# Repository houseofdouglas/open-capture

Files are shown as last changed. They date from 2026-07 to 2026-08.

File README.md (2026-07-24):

# open-capture

A fully DIY object-scanning setup for turning real objects into 3D-printable
replicas — **no LiDAR, no NVIDIA GPU, no paid software**. A phone camera plus
a printed motorized turntable feed Apple's built-in photogrammetry engine,
and the result is cleaned up into a printable STL.

It has two halves:

1. **`photogrammetry`** — a tiny macOS command-line wrapper around Apple's
   RealityKit Object Capture. Point it at a folder of photos, get a 3D model.
2. **`scanner_rig/`** — a printable, motorized photogrammetry rig: a turntable
   driven by a 28BYJ-48 stepper and an iPhone cradle, with an ESP32 that
   rotates the table and fires the camera shutter over Bluetooth. One button
   press = one full revolution of evenly spaced photos, hands-free.

## Pipeline

```
object on turntable  ──►  ~144 photos (3 tilt orbits)  ──►  photogrammetry CLI
      ──►  .usdz mesh  ──►  Blender cleanup  ──►  STL  ──►  slice & print
```

## Quick start (software)

Build the photogrammetry CLI (macOS, Apple silicon, Xcode toolchain):

```bash
swiftc -O -parse-as-library -o photogrammetry photogrammetry.swift
```

Reconstruct a model from a folder of photos:

```bash
./photogrammetry ./photos ./model.usdz -d full -f high
```

`-d` detail: `preview | reduced | medium | full | raw`  ·  `-f` feature
sensitivity: `normal | high`. Run a quick `-d medium` pass first to check
photo coverage before committing to a long `full` run.

## The rig

See **[`scanner_rig/README.md`](scanner_rig/README.md)** for the bill of
materials (~$15 of electronics), print list, wiring, and assembly. All parts
are parametric OpenSCAD and print without supports. Firmware and the exact,
verified library versions are in
**[`scanner_rig/firmware/turntable_shutter/`](scanner_rig/firmware/turntable_shutter/)**
(see `LIBRARIES.md` there — the ESP32-C3 needs the NimBLE keyboard stack).

## Capture tips (these matter more than the software)

- Even, diffuse light; matte-coat shiny or featureless objects.
- A **plain, featureless backdrop** behind the turntable — if the software can
  see background texture, it concludes the object never moved and the
  reconstruction fails.
- Lots of overlapping photos from several heights (the cradle's tilt stops).
- Include a ruler in a couple of shots so you can scale the model correctly.

## License

MIT — see [`LICENSE`](LICENSE).

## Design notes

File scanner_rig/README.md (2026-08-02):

# Automated Photogrammetry Scanning Rig

Motorized turntable + tilting iPhone 16 Pro cradle for Object Capture
scans. The ESP32 rotates the table and triggers the iPhone shutter over
Bluetooth (it emulates a volume-up keypress — the native Camera app's
shutter). One button press = one full revolution of evenly spaced photos.

## Bill of materials

| Item | Qty | Notes |
|---|---|---|
| 28BYJ-48 stepper + ULN2003 driver | 1 | sold as a pair, ~$4 |
| ESP32-C3 SuperMini | 1 | 22.52 x 18 mm, 2.54 mm pitch headers |
| 608ZZ bearings (skateboard) | 3 | platter support rollers |
| (printed axle x3) | 3 | snap-in bearing axles — no rod/bolt needed |
| M4 x 8 screws + nuts | 2 | motor ears, bolted through the hub (nut underneath) |
| Zip ties | 2 | lash the ULN2003 board to a spoke |
| M4 x 12 screws | 3 | 2 pivots + 1 angle-lock pin (self-tap into tray bosses) |
| M4 x 12 screws | 4 | crossbars, through each wing into the bar ends (self-tap) |
| M4 x 12 screws | 6 | roller brackets, up through the plate (self-tap into bracket feet) |
| USB cable + 5 V supply | 1 | powers ESP32 and motor |
| Cork or rubber sheet, ~175 mm disc | 1 | optional platter grip, glued to the top face |

## Print

All parts print without supports. PLA or PETG, 3–4 walls, ~25% infill.
PETG note: drive the self-tapping M4 screws slowly — PETG grips hard and
can crack a boss if forced; the pilot holes are sized 3.6 mm for it.

The wing is 238 x 312 mm, so print the two **one at a time** — they won't fit
side by side on a 350 mm bed. Use a brim: it's a long, thin, flat PETG part and
the corners are the most likely thing to lift.

The base is a lightweight spoked frame (motor hub + bracket ring + 3 spokes
+ 3 feet) — about half the filament of a solid disc. Set `solid_base = true`
in `turntable.scad` if you'd rather have the fully enclosed disc + skirt.

| File | Part | Orientation |
|---|---|---|
| `turntable.scad` | `motor_test` (`stl/turntable_motor_test.stl`) | OPTIONAL: dry-fit the motor first (see below) |
| `turntable.scad` | `base_print` (`stl/turntable_base_print.stl`) | pre-flipped: plate face down, skirt up |
| `turntable.scad` | `bracket` x3 (`stl/turntable_bracket.stl`) | foot down |
| `turntable.scad` | `axle` x3 (`stl/turntable_axle.stl`) | flange on the bed, tip up |
| `turntable.scad` | `platter` | **upside down** (hub boss up) — or use `platter_print` / `stl/turntable_platter_print.stl`, which is pre-flipped |
| `phone_cradle.scad` | `tray` | flat on its back |
| `phone_cradle.scad` | `wing` x2 (`stl/cradle_arc_wing.stl`) | flat (238 x 312 x 6) |
| `phone_cradle.scad` | `crossbar` x2 (`stl/cradle_arc_crossbar.stl`) | flat |
| `phone_cradle.scad` | `gauge` (`stl/cradle_setback_gauge.stl`) | flat — holds the stand's setback, see below |
| `phone_cradle.scad` | `chocks` (`stl/cradle_foot_chocks.stl`) | one print = both chocks; locks the position outright |
| `phone_cradle.scad` | `shim` x2 (`stl/cradle_arc_shim.stl`) | only for taller objects — see below |
| `phone_cradle.scad` | `gauge` x1 (`stl/cradle_setback_gauge.stl`) | sets turntable↔stand distance repeatably |
| `phone_cradle.scad` | `chocks` x1 file (`stl/cradle_foot_chocks.stl`) | lock the turntable foot once aligned |

(`stand` is the older flat stand — superseded by the arc wings, see below.)
| `header_pin_jig.scad` (`stl/header_pin_jig.stl`) | OPTIONAL: solder the ESP32-C3 SuperMini's header pins | flat on the bed |

Export from the CLI: `openscad -o platter.stl -D 'part="platter"' turntable.scad`
(pre-exported copies are in `stl/`).

**Soldering the SuperMini's header pins:** print `header_pin_jig.scad`. Snap
two 1x8 segments off a standard break-away header strip and push each,
long-pin-down, into a row of the jig's holes until the plastic shoulder
sits flat on top — same as plugging them into a breadboard. The short pins
now point up ~2.5 mm; lower the SuperMini (component side up) so its two
rows of through-holes slide over them, tack-solder one corner pin per row,
check it sits flat and square, then solder the rest from the top.

Dry-fit before reprinting the base: print `motor_test` and check that
(1) the shaft passes through the center hole, (2) the body drops into the
recess and can rotate freely to any angle, and (3) both ear bolts pass
through the holes with the ears flat. If an ear is off, tweak `mount_c2c`
(spacing) or `mount_perp` (offset) and reprint the coupon until it fits —
then the full base is guaranteed right.

Key parameters to check before printing:

- `turntable.scad` → `shaft_len`: measure your motor's shaft protrusion
  above the mounting flange (typically ~10 mm).
- `phone_cradle.scad` → `fit` / `phone_t`: bump to ~2.0 / case thickness
  if the phone wears a case.
- `phone_cradle.scad` → `obj_h`: where the arc aims — the height of the object's
  **centre** above the table, `69 + objectHeight/2`. Default 101 targets a 64 mm
  object (the 2x sweet spot). **You don't need a wing per object size** — see
  One stand, any object size below.
- `phone_cradle.scad` → `cam_R`: camera-to-object distance. Leave at 200 mm and
  change **zoom** rather than geometry to handle different object sizes — see
  Framing below. This sets the size of the wings, so pick it before printing.

## Why the stand is an arc

Tilting the tray only changes where the camera *aims*, not where it *is*. A
cradle fixed at object height shooting 40° down aims at the tabletop in front
of the object. To shoot down at θ and keep the object centred and the same size
in frame, the camera has to ride an arc of constant radius about the object
centre:

```
y = cam_R·cos θ        z = obj_h + cam_R·sin θ        tilt = θ
```

Higher **and** closer as θ grows. Besides framing, that's also what keeps the
stand short — reaching 65° on an arc needs 271 mm of height, but a straight
column 200 mm back would need **519 mm**:

| elevation | arc: dist / height | straight column: height |
|---|---|---|
| 15° | 193 mm / 142 mm | 144 mm |
| 40° | 153 mm / 219 mm | 258 mm |
| 65° | 85 mm / 271 mm | 519 mm |

The wings' three pivot stations sit on that arc, each with a lock hole that
sets the matching tilt, so the geometry can't be set wrong. Verified in CAD:
the tray clears the wings and crossbars at all three stations, and the stand
stays stable (worst-case CG 23 mm inside the front foot).

## Assemble

**Reusing an already-printed base** (motor and bracket-screw holes moved in
this revision — you do NOT need to reprint the big base): the safest way to
locate the new holes is to use the parts themselves as drill templates.
- Motor: print `motor_drill_template.scad` (`stl/motor_drill_template.stl`).
  Flip it onto the flat plate face — its center pin drops into the shaft
  hole and its locator pin into an old ear hole, fixing position AND
  rotation. Drill through the two guides with a 4.4 mm bit. Old holes stay
  unused. (More precise than free-hand marking through the ears.)
- Brackets: centre a new (reprinted) bracket over each old hole pair, mark
  through its two foot holes, drill Ø4.4. This puts the screws fore & aft
  of the bearing where they belong.
Only the **brackets** must be reprinted (the old ones bury the bearing on
the foot and put screws under it). The platter is fine as-is; reprint it
only if shaft engagement feels shallow.

1. Mount the motor: shaft up through the center hole, body in the recess.
   The 28BYJ-48 shaft is OFFSET from the body centre, so the recess is
   oversized and centred on the shaft — rotate the motor so its two ears
   lie over the bolt holes, then bolt through with M4 x 8 + nuts. (The
   motor carries no load, it only turns the platter, so light retention
   is enough.)
2. Drop a 608ZZ into each bracket's gap and push a printed `axle` through
   from the outer tab — barb first — until it clicks past the far tab and
   the flange seats flush. The bearing spins on the shaft; no rod or bolt
   needed. Screw the three brackets to the plate top with M4 x 12 from
   underneath — the two screws sit fore & aft of the bearing so they can't
   foul it, and the foot is relieved beneath the bearing so the outer race
   spins free.
3. Press the platter's hub onto the D-shaft; its rim rests on the bearings.
   The platter's weight sits on the three bearings, not the motor shaft.
4. Bolt the tray between the uprights (M4 pivots through the big holes,
   self-tapping into the tray bosses). The third M4 through an arc hole
   into the tray's lock hole sets the tilt. Both long walls are relieved
   so the phone's side buttons never get pressed — slide the phone in
   under the two retaining tabs; either orientation works. The window
   is sized so the camera island passes through it and the phone seats
   on the flat glass around it (rather than rocking on the lenses).
5. Wire the ULN2003 (IN1/2/3/4 → GPIO 4/5/6/7, 5 V, GND) and zip-tie the
   board to one of the spokes; the motor and wiring hang in the open frame
   below the platter.

   Bring-up tip: if you want to check the motor and coil wiring before
   committing to the ESP32, `firmware/uno_r4_stepper_test/` runs the same
   coil sequence on an Arduino Uno R4 (IN1-4 → D8-D11) — press a button on
   D2, or type `r` in Serial Monitor, for one revolution. Once that spins
   smoothly, move IN1-4 to the ESP32 GPIOs above and flash
   `turntable_shutter` for real.

   Have a Uno R4 **WiFi**? Its connectivity module is itself a standalone
   ESP32-S3 with its own USB-JTAG/Serial port — `firmware/uno_r4_esp32s3_shutter_test/`
   can be flashed directly onto it (bypassing the RA4M1 main chip entirely)
   to test the BLE-keyboard shutter trick before wiring up the SuperMini.
   See that file's header comment for how to enter direct-flash mode.

## One stand, any object size

`obj_h` is baked into the wings, but it only fixes where the arc *aims*. What
actually matters is the height difference between the wings' base and the object
centre — so change that with a shim instead of reprinting a stand:

```
shim = (object height)/2 + 69 − obj_h      (69 = platter top above the desk)
```

- **positive** → spacer under both wings (`shim` part; set `shim_rise`, print 2)
- **negative** → riser under the object, on the platter (any disc of that height)

At the default `obj_h = 101`:

| object height | shim |
|---|---|
| 20 mm | 22 mm riser under the object |
| 40 mm | 12 mm riser under the object |
| **64 mm** | **none — exact** |
| 80 mm | 8 mm under the wings |
| 100 mm | 18 mm under the wings |
| 130 mm | 33 mm under the wings |
| 160 mm | 48 mm under the wings |

And you can ignore the shim entirely over a useful range, because the object just
sits slightly off-centre in frame rather than badly misaimed: **no shim needed
for 43–85 mm objects at 2x, or 23–105 mm at 1x** (the wider 1x frame is more
forgiving). Only reach for a shim outside those bands.

## Framing — how much of the frame the object should fill

Apple's rule is "maximize the portion of the field of view capturing the
object", but "each image should contain the entirety of the object". For a
turntable that needs one extra constraint: **the object rotates**, so you have
to frame its *widest* rotational profile, not the width you happen to see when
setting up.

**Target ~65% of the short (vertical) frame dimension at the object's widest
rotation.** To check it, **double-press the BOOT button**: the table makes one
full revolution in ~10 s with no photos, so you can watch the preview and
confirm nothing clips at any angle. (Works with no phone paired too, for
exercising the mechanism.)

- Below ~50%: throwing away resolution.
- Above ~80%: the object clips on some rotations, and it sits in the
  lens-distortion zone at the frame edges. Clipped frames cost more than the
  extra detail gains.

At `cam_R = 200 mm`, the vertical frame is almost exactly the camera distance
at 1x, and half that at 2x:

| zoom | vertical frame | detail | 65% fill = object |
|---|---|---|---|
| **1x** (24 mm eq, 24 MP) | 199 mm | 21 px/mm | **130 mm** |
| **2x** (48 mm eq, 12 MP) | 100 mm | 30 px/mm | **65 mm** |

So one printed stand covers roughly **50–160 mm** objects just by switching
zoom — and 2x actually resolves *more* detail per mm than 1x, because it's a
true sensor crop of the 48 MP main camera (not interpolation). Smaller objects
still work at reduced fill: a 30 mm object at 2x is ~900 px across, plenty for
a good mesh. Avoid the 5x lens — it's a separate camera with a much longer
minimum focus distance.

**Keep the zoom locked and identical for all 144 shots** of a session, along
with focus and exposure — Apple asks for consistent focal length, shutter,
aperture and ISO across the set. Never change zoom mid-session.

### Holding the setback (`stl/cradle_setback_gauge.stl`, print 1)

Re-pinning the tray between stations nudges the stand, and any change in setback
changes `cam_R` — so scale, framing and focus distance drift between passes,
which is exactly what the arc exists to prevent.

The gauge is a bar that drops over both wing toes (a slot either side of each
bottom rail) and presents a flat face 11 mm in front of them. Turn the turntable
so **one foot points at the stand**, push it back until that foot touches the
face, and the platter axis is 100 mm from the toes — by geometry, not by eye.

Two things about it are deliberate:

- **The contact is flat, not a pocket.** A flat only fixes fore/aft, so you can
  still slide the turntable sideways to put the lens on the axis (below). A
  pocket capturing the foot would fix the sideways offset too and make the
  ~45–50 mm lens offset unreachable.
- **Aim is forgiving.** As the foot rotates its outer corner sweeps toward the
  contact, so being 10° off costs under 0.2 mm of setback (20° ≈ 1.8 mm). It
  does not need to be squared up carefully.

Verified in CAD: at the stop it touches the foot with zero interference, clears
both wings and the platter, and still clears after sliding the turntable 50 mm
sideways. Print flat as modelled — no supports.

### Locking the position outright (`stl/cradle_foot_chocks.stl`, one print = 2 parts)

The gauge alone only stops the turntable moving *closer*. It can still slide
sideways or pull away, so knocking the stand while re-pinning the tray still
changes the framing and the next pass no longer matches the last.

The chocks finish the job. They are a C-clamp that drops onto the gauge bar from
above (anywhere along it — they never have to slide past the wing-rail guides)
and clamp either side of the captured foot with an M4 self-tap screw:

| direction | what stops it |
|---|---|
| fore | the gauge's flat face on the foot's outer face |
| aft | the chocks' inward hooks catching the foot's inner face |
| lateral | the two chock side faces pinching the foot |
| yaw | those same two faces holding the foot square |

**Yaw is the one that is easy to miss.** The platter axis is located
*indirectly*, 80 mm inboard of the foot, so letting the base rotate swings the
axis even with the foot's position perfectly fixed. That is why the foot is
gripped on both sides rather than simply cornered.

Set them **once, after the lens alignment**, and the sideways offset is
preserved — they clamp anywhere along the bar, so nothing hard-codes an offset
specific to one phone or one landscape orientation. To re-align later, slacken
both screws, slide, retighten.

Drive the screws from **behind**: the reaction pulls the collar onto the bar. A
screw pressing down from the top would jack the chock off it instead.

Measured slack in CAD — seated with zero interference, and colliding as soon as
it moves:

| movement | free until | residual effect |
|---|---|---|
| lateral | 0.5 mm | 0.14° off-axis — negligible |
| pull away | 0.5 mm | 0.25% scale error |
| yaw | under 0.5° | swings the axis 0.7 mm |

Worst case that is ~1.2 mm of axis error, **0.9% of the 133 mm frame width at
2x** — comfortably below what shows up between passes.

To remove the turntable, just lift it out; the hooks are only 12 mm tall against
a 32 mm foot.

### Aligning the lens with the turntable axis

The arc is centred on the tray's pivot, but the iPhone's rear lens is **not** at
the centre of the phone — the camera island sits near one end, roughly 45–50 mm
off centre along the phone's long axis. In landscape that offset is sideways, so
if you line the *stand* up with the turntable axis, the object lands well off
centre in the frame (~14° off axis at 200 mm — near the edge at 2x).

Fix at setup, no parts change: **slide the turntable sideways until the object
is centred in the camera preview**, then mark the spot. Aligning the lens (not
the stand) with the platter axis also makes the camera-to-object distance
exactly `cam_R`. There's a smaller ~9 mm vertical offset too; nudge the
turntable or `obj_h` if the object sits high or low in frame.

Overlap is already comfortable: 48 shots/revolution = 7.5° steps ≈ 96% overlap
between adjacent frames (Apple's minimum is 70%), and 3 orbits × 48 = 144
images (Apple's minimum is 100).

## Uneven advances — drive-train backlash

Symptom: stepping through the shots, some advances look full and others fall
short, at random.

The cause is lost motion between the motor and the platter, and it is much
larger than it looks. The platter's D-bore rides the 28BYJ-48's flatted shaft
with 0.4 mm of clearance across a 3 mm flat — a 1.5 mm moment arm, so that tiny
linear clearance becomes **~6° of free rotation, about 80% of a 7.5° photo
step.** The motor's own plastic gear train adds more on top.

| bore flats | clearance | free rotation | of a 7.5° step |
|---|---|---|---|
| 3.4 (original) | 0.40 mm | 5.97° | 80% |
| 3.2 | 0.20 mm | 2.92° | 39% |
| 3.1 | 0.10 mm | 1.45° | 19% |

Three fixes, in order of effect:

1. **Grub screw in the hub (removes the play, doesn't just shrink it).**
   `hub_grub` adds a radial M3 into the boss, clamping the shaft's flat against
   the opposite bore flat. **No reprint needed** — the boss is Ø18 around a
   Ø5.4 bore, so there is 7.3 mm of wall. Drill Ø2.5 radially at mid-boss
   height on an already-printed platter and run an M3 grub screw in.
2. **Hold the coils for the whole revolution.** The firmware used to cut the
   coils after *every* increment, so during the 3.3 s of settle + exposure the
   rotor had no holding torque and the platter relaxed back into the slack;
   the next move then spent part of its travel re-taking it up. Turning one
   direction only, the slack is taken up **once** — but only while the rotor is
   held. Coils now release only at the end of the run. Costs ~200 mA per
   energised phase and the motor runs warm, well inside its continuous rating.
3. **Pre-load before the first shot.** `BACKLASH_STEPS` (100 half-steps ≈ 8.8°)
   runs in the same direction as the revolution before frame 1, so the first
   advances aren't short while the backlash closes. Those steps are not counted
   against `STEPS_PER_REV` — they buy motion in the mechanism, not rotation.

Tightening `shaft_flats` helps but never reaches zero and risks a bore too tight
to assemble, which is why the screw is the primary fix.

## Scan workflow

1. Flash `firmware/turntable_shutter/` (Arduino IDE, ESP32 board package,
   "ESP32 BLE Keyboard" library). Pair **ScanTable** in iPhone Bluetooth
   settings.
2. Place the turntable ~25–35 cm in front of the cradle (object should
   fill ~70% of the frame; use 2x at ~50 cm for small objects). Even,
   diffuse lighting on all sides — your lighting kit, or a light tent.
   Matte-coat shiny objects (dry shampoo / scanning spray).
3. Open the Camera app, lock focus/exposure (long-press → AE/AF LOCK). Then
   **double-press BOOT** for a photo-free revolution and watch that the object
   stays in frame all the way round before committing to a real scan.
4. Tray on the lowest arc station (15°) → press the ESP32 button → 48 photos.
   Move the tray's 3 screws to the 40° station, repeat; then 65°. ≈144 photos.
   Set `obj_h` so the arc is centred on your object, and re-check framing at
   the first station — all three stations then frame identically.

   **Or mount up to three phones and do it in one revolution.** The firmware
   drives whatever is paired, 1 to 3 — there is nothing to configure and no
   reflash to change the count. It keeps advertising while a slot is free, so a
   phone can be added or dropped at any time, including between revolutions;
   each run simply fires whichever are connected. With one tray per station
   (they clear each other by 6.5 mm, and the stand is stable at ~1 kg) a single
   revolution captures all 144 photos — ~2.5 min instead of ~8, with no
   re-pinning.

   A BLE HID notify reaches every subscribed host, so one keypress fires them
   all; the table stands still ~3 s per step, so sync tolerance is about a
   second, not milliseconds. Pair the phones **one at a time**, waiting for each
   `phone connected — n of up to 3` line before starting the next.

   Caveats: every phone needs the Camera app frontmost with AE/AF and zoom
   locked; identical models are preferable so the camera intrinsics match; and
   a tray sized per model if the phones differ (the tray is parametric). Three
   phones need the raised CCCD store — see `firmware/turntable_shutter/
   LIBRARIES.md`; a `static_assert` fails the build if it's missing. If iOS
   refuses the second or third pairing, fall back to one ESP32 per phone with a
   shared GPIO trigger line — the ~1 s tolerance makes that easy.
5. AirDrop the photos to the Mac and reconstruct:

   ```sh
   ./photogrammetry ./photos ./model.usdz -d full -f high
   ```

6. Blender: import USDZ → voxel remesh → selective smooth → fix
   non-manifold → scale check → export STL → slice.

Note: turntable scans defeat Object Capture's automatic background
separation only if the background is textured. Use a plain featureless
backdrop (paper sweep) so the only thing that appears to move is the
object — this is what the plain platter and backdrop are for.

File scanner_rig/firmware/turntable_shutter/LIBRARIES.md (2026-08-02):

# Firmware library setup (turntable_shutter)

Records the exact toolchain that compiles `turntable_shutter.ino` cleanly for
the **ESP32-C3 SuperMini**. Reproduce this on a fresh machine and the sketch
builds (verified: `arduino-cli compile --fqbn esp32:esp32:esp32c3`, exit 0).

## Versions

| Component | Version | Notes |
|---|---|---|
| ESP32 Arduino core (`esp32:esp32`) | **3.3.11** | NimBLE 2.x requires core 3.x |
| NimBLE-Arduino | **2.5.0** | https://github.com/h2zero/NimBLE-Arduino |
| ESP32-NimBLE-Keyboard (fork) | commit **1f3a88a** | https://github.com/wakwak-koba/ESP32-NimBLE-Keyboard |

Board in Arduino IDE: **ESP32C3 Dev Module** (FQBN `esp32:esp32:esp32c3`).

## Why not the usual library

The common **T-vK `ESP32 BLE Keyboard`** (Bluedroid) **panics at boot** on the
ESP32-C3 — `Guru Meditation … Load access fault`, null deref (MTVAL 0x2c) in
NimBLE HID setup during `bleKeyboard.begin()`. It's a documented C3
incompatibility. The NimBLE fork above is a drop-in (same `<BleKeyboard.h>`
and API, incl. `KEY_MEDIA_VOLUME_UP`) but runs on the stack the C3 supports.

## Install

1. Arduino IDE Library Manager → install **NimBLE-Arduino 2.5.x**.
2. Install the keyboard fork (no releases — clone master):
   ```
   git clone https://github.com/wakwak-koba/ESP32-NimBLE-Keyboard.git \
     ~/Documents/Arduino/libraries/ESP32-NimBLE-Keyboard
   ```
3. **Remove/move out** the T-vK `ESP32-BLE-Keyboard` so its `BleKeyboard.h`
   isn't picked up instead. (Ours is parked in
   `~/Documents/Arduino/_disabled_libraries/`.)

## Required patch (one line)

The fork's master uses `std::function` without including it, which NimBLE
1.4.x pulled in transitively but 2.x does not. Without this, the build fails
with `'function' in namespace 'std' does not name a template type`.

In `ESP32-NimBLE-Keyboard/src/BleKeyboard.h`, after `#include <Print.h>`, add:

```cpp
#include <functional>   // for std::function (Callback); not transitive on NimBLE 2.x
```

**This patch is lost if the library is updated/re-cloned — re-add the line.**

## Second patch — multi-phone support (only if PHONES > 1)

The library marks itself disconnected as soon as *any* host drops, which would
stop the shutter for the remaining phones. In
`ESP32-NimBLE-Keyboard/src/BleKeyboard.cpp`, in
`onDisconnect(NimBLEServer*, NimBLEConnInfo&, int)`:

```cpp
// was: connected = false;
connected = pServer->getConnectedCount() > 0;
```

Nothing else is needed for multi-host, and `NimBLECharacteristic::notify()` with
the default handle sends "to all subscribed clients" — so one keypress fires
every paired phone.

Also lost on library update — re-add it.

### Serial monitor is blank → USB CDC On Boot

The ESP32-C3 SuperMini has **no USB-UART bridge**; it uses the C3's native USB
Serial/JTAG (it enumerates as `/dev/cu.usbmodem*`, not `cu.usbserial*`). The
board's default is `CDCOnBoot=Disabled` (`boards.txt`: `esp32c3.menu.CDCOnBoot
.default=Disabled`), which routes `Serial` to **UART0 on GPIO 20/21** — pins
with nothing attached. Upload works, the sketch runs, the monitor stays empty.

Fix: **Tools → USB CDC On Boot → Enabled**, then reflash. On the CLI:

```
arduino-cli compile --fqbn esp32:esp32:esp32c3:CDCOnBoot=cdc turntable_shutter
arduino-cli upload  --fqbn esp32:esp32:esp32c3:CDCOnBoot=cdc -p /dev/cu.usbmodemXXXX turntable_shutter
```

The plain `esp32:esp32:esp32c3` FQBN silently builds with CDC off.

Also note the host enumerates the CDC port a beat *after* boot, so prints issued
immediately in `setup()` are lost even when CDC is on. The sketch waits up to
2 s for `Serial` — bounded, so the rig still runs untethered.

### Verified connection ceilings (three phones IS supported)

If a third phone won't connect, it is **not** a configured limit — checked
against what's actually installed:

| layer | setting | value |
|---|---|---|
| NimBLE-Arduino 2.5.0 | `src/nimconfig.h` | `MAX_CONNECTIONS 3`, `MAX_BONDS 3` |
| esp32 core 3.3.11 (C3) | `tools/esp32c3-libs/3.3.11/sdkconfig` | `BT_NIMBLE_MAX_CONNECTIONS=3`, `BT_NIMBLE_MAX_BONDS=3` |
| C3 BLE controller | same sdkconfig | `BT_CTRL_BLE_MAX_ACT=6` |

Note 3 is the **hard ceiling** on simultaneous connections — a 4th phone needs
`CONFIG_BT_NIMBLE_MAX_CONNECTIONS` raised in `nimconfig.h` (a patch lost on
library update).

### Why the third phone fails even though 3 connections are allowed

**This is the actual cause of "only two phones will pair."** Connection count is
not the binding limit — the **CCCD store** is.

Every bonded host stores one CCCD record per notify characteristic it subscribes
to, and NimBLE keeps them all in **one global array shared by every bond**, not
per-peer:

```c
// nimble/host/store/config/src/ble_store_config.c:47
struct ble_store_value_cccd ble_store_config_cccds[MYNEWT_VAL(BLE_STORE_MAX_CCCDS)];
```

This HID device exposes exactly **3 notify characteristics** — keyboard input
report, media-key input report (`NimBLEHIDDevice::getInputReport`, `NOTIFY`), and
battery level (`NimBLEHIDDevice.cpp:64`, `READ | NOTIFY`). So N phones need 3N
records against a default of 8:

| phones | CCCDs needed | fits in 8? |
|---|---|---|
| 2 | 6 | yes |
| 3 | 9 | **no — store overflows** |

Hence exactly two phones, every time, with no error on the ESP32 side.

### The override must target `MYNEWT_VAL_BLE_STORE_MAX_CCCDS`

`build_opt.h` (sitting next to the `.ino`; the esp32 core copies it in via a
prebuild hook and appends its lines as compiler flags) carries:

```
-DMYNEWT_VAL_BLE_STORE_MAX_CCCDS=16
-DMYNEWT_VAL_BLE_STORE_MAX_BONDS=5
```

Do **not** try to override `CONFIG_BT_NIMBLE_MAX_CCCDS` instead — it silently
does nothing. `nimconfig.h:4` does `#include "sdkconfig.h"` on `ESP_PLATFORM`,
and the core's sdkconfig defines `CONFIG_BT_NIMBLE_MAX_CCCDS=8` *unconditionally*,
clobbering any `-D`. The `MYNEWT_VAL_` alias is `#ifndef`-guarded in both places
that define it (`esp_nimble_cfg.h:989`, `syscfg.h:1104`), so a command-line
define wins there.

The bond bump to 5 is headroom, not a strict requirement: `MAX_BONDS` defaults to
3, which fits three phones *exactly* — one stale bond from a re-pair or a
retired phone and the next pairing fails.

A `static_assert` in the sketch enforces `MYNEWT_VAL_BLE_STORE_MAX_CCCDS >=
3 * PHONES`, so losing `build_opt.h` is a build error rather than a silent
regression to two phones. **Unlike the library patches above, this one lives in
the sketch folder and survives library updates.**

Verify it took effect from the RAM figure — the CCCD bump alone moves global
variables by +128 bytes (8 extra records x 16 bytes).

### Advertising must be restarted from `loop()`, not from the callback

The library stops advertising when a host connects, so phones 2 and 3 need it
restarted. Do **not** do that inside `bleKeyboard.onConnect(...)`: that callback
runs in the NimBLE host task while the connect event is still being processed,
`NimBLEDevice::startAdvertising()` returns `bool` and can fail there, and a lost
restart is unrecoverable — the next phone never sees an advertisement and you
are stuck at two phones forever.

The sketch instead calls `keepAdvertising()` every `loop()`, which restarts
advertising whenever `getConnectedCount() < PHONES` and the radio is idle, so a
failed attempt is simply retried.

For the same reason the sketch never hand-counts hosts. iOS HID pairing does
connect → bond → reconnect, so connect/disconnect callbacks do not reliably pair
up; a counter drifts, reads 3 with two phones attached, and permanently
suppresses advertising. `hostsUp()` asks the server via `getConnectedCount()`.

## Pitfalls to avoid

- **NimBLE 1.4.x + this fork** → `marked 'override', but does not override`
  (1.x callbacks lack the `NimBLEConnInfo&` param). Use NimBLE **2.x**.
- **NimBLE 2.x without the `<functional>` patch** → the `std::function` error
  above.
- **GPIO 8** for a stepper coil → it's a C3 strapping pin (and usually the
  onboard LED); can wedge boot. Sketch uses GPIO 4–7 for the coils, 9 for BOOT.

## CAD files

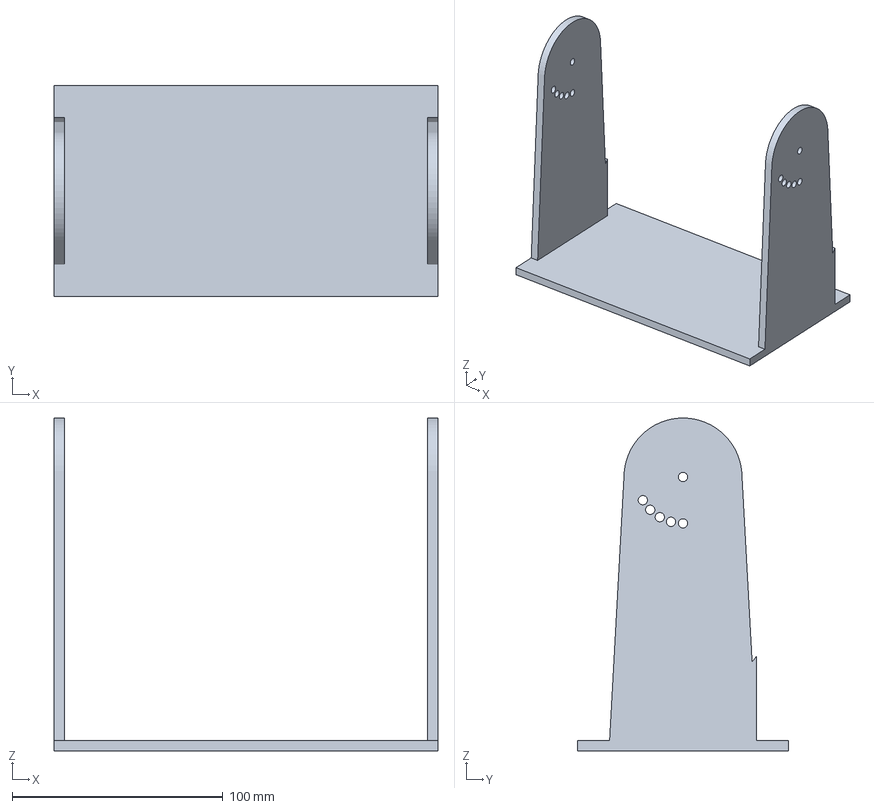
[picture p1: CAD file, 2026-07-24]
scanner_rig/cradle_stand.3mf
182.2 x 100.0 x 158.0 mm

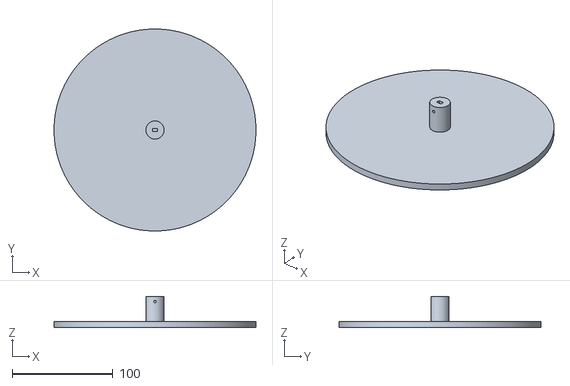
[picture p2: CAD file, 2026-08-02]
scanner_rig/stl/turntable_platter_print.stl
200.0 x 200.0 x 31.0

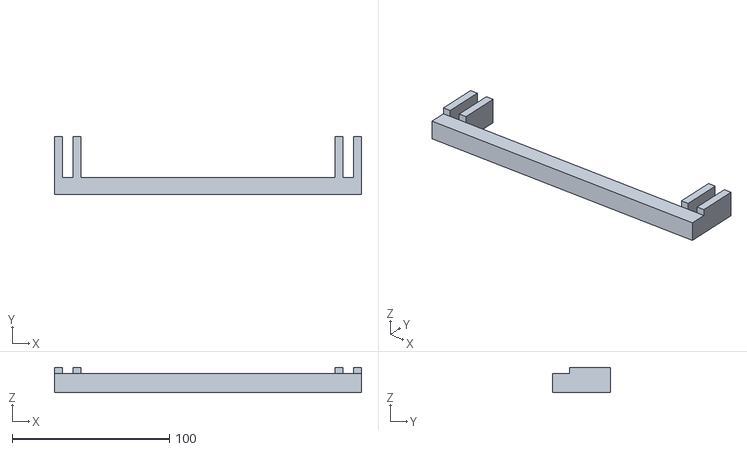
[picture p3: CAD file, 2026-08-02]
scanner_rig/stl/cradle_setback_gauge.stl
195.0 x 37.0 x 16.0

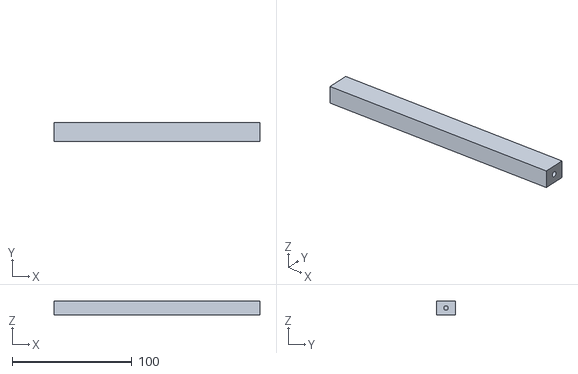
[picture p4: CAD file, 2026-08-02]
scanner_rig/stl/cradle_arc_crossbar.stl
172.2 x 16.0 x 12.0

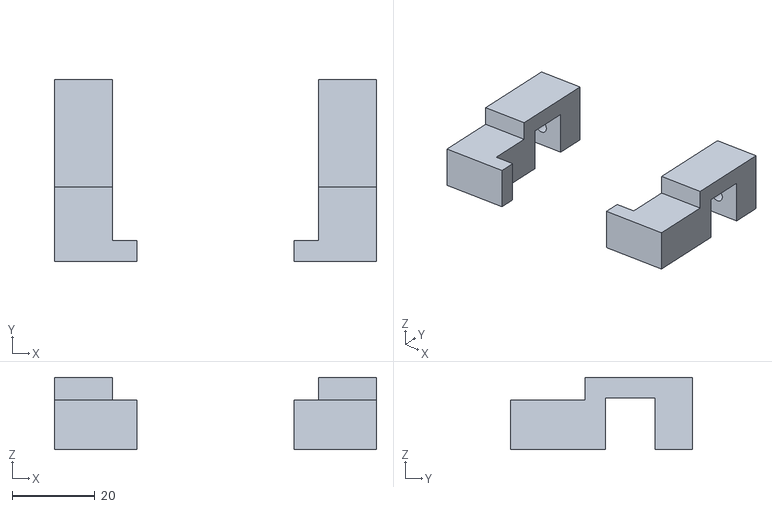
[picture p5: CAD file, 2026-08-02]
scanner_rig/stl/cradle_foot_chocks.stl
78.0 x 44.0 x 17.5

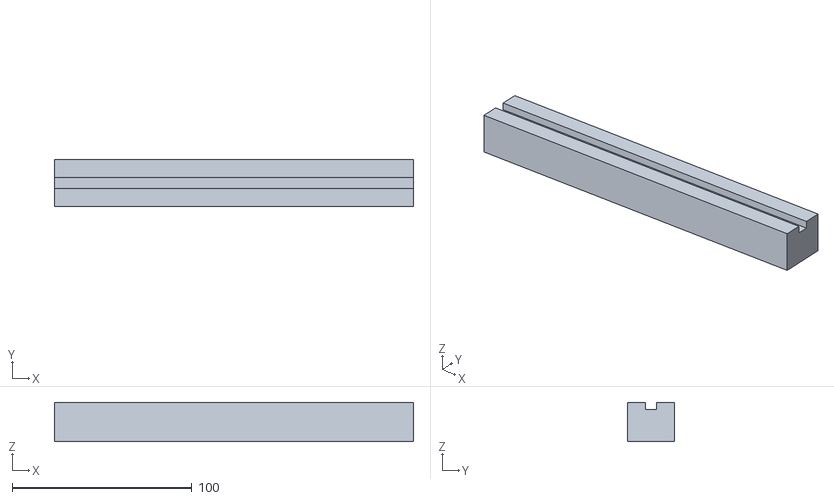
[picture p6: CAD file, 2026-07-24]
scanner_rig/stl/cradle_arc_shim.stl
200.0 x 26.0 x 22.0

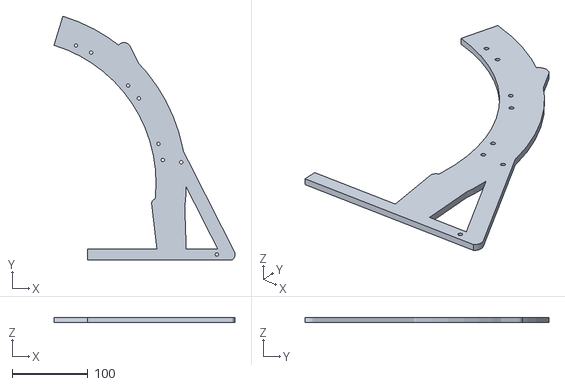
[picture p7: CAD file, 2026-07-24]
scanner_rig/stl/cradle_arc_wing.stl
238.5 x 320.9 x 6.00

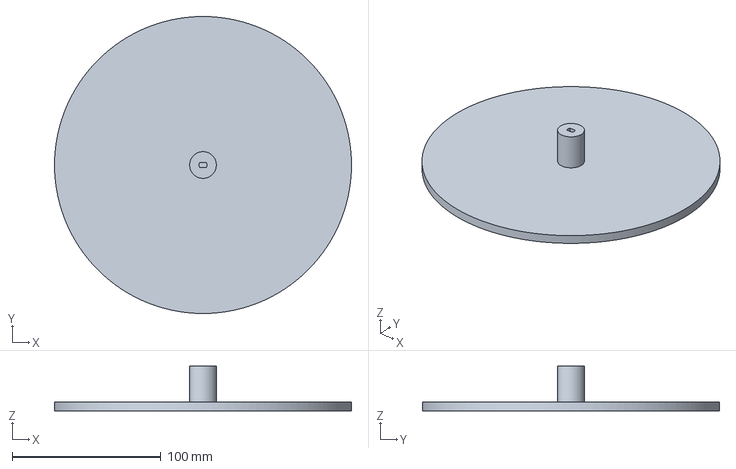
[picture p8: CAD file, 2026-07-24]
scanner_rig/stl/turntable.3mf
200.0 x 200.0 x 30.0 mm

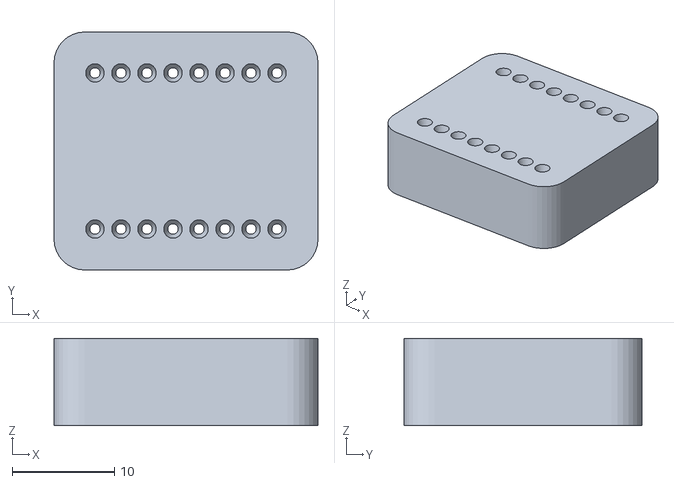
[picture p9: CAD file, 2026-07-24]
scanner_rig/stl/header_pin_jig.stl
25.8 x 23.2 x 8.50

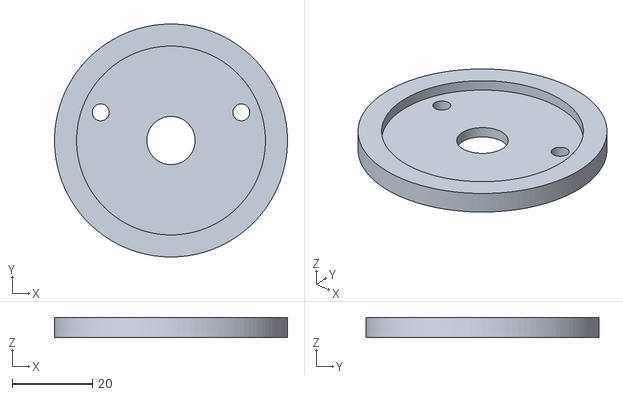
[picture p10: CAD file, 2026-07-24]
scanner_rig/stl/turntable_motor_test.stl
58.0 x 58.0 x 5.00

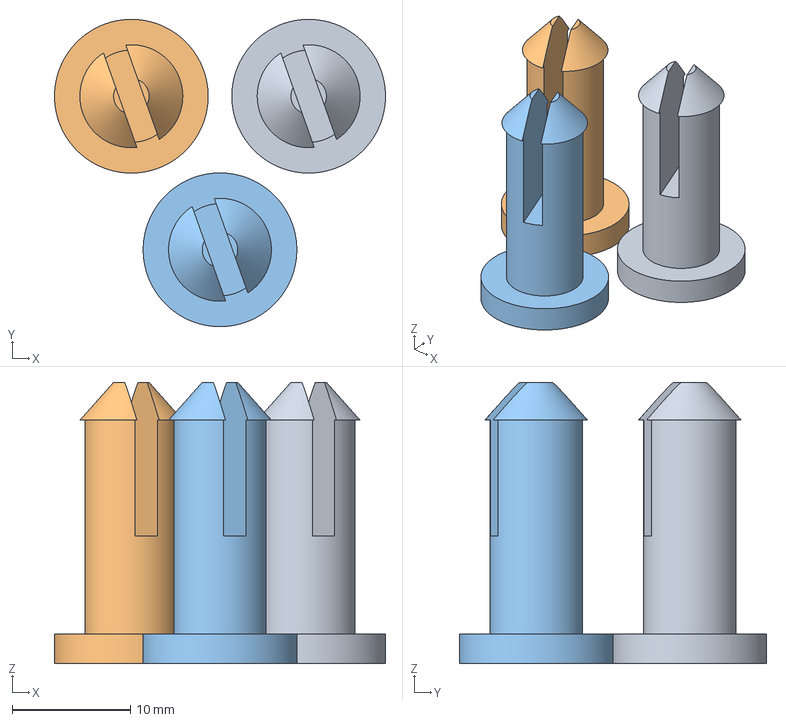
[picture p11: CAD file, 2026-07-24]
scanner_rig/stl/turntable_axle.3mf
28.0 x 26.0 x 23.8 mm
turntable_axle.stl x 3

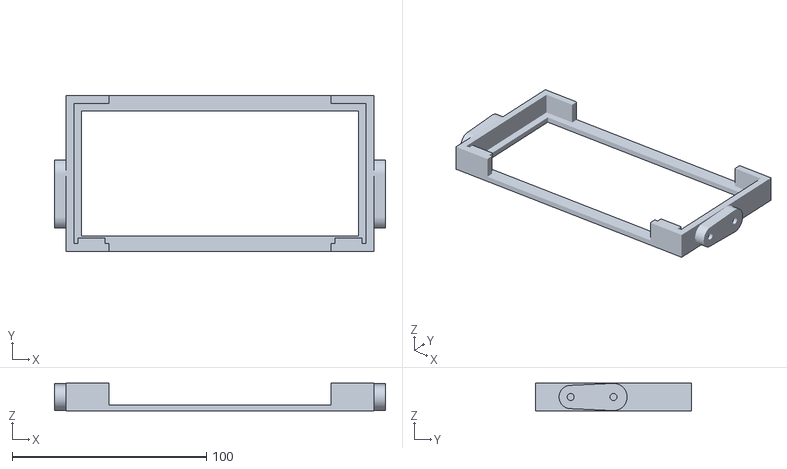
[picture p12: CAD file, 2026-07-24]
scanner_rig/stl/cradle_tray.stl
170.2 x 80.1 x 14.2

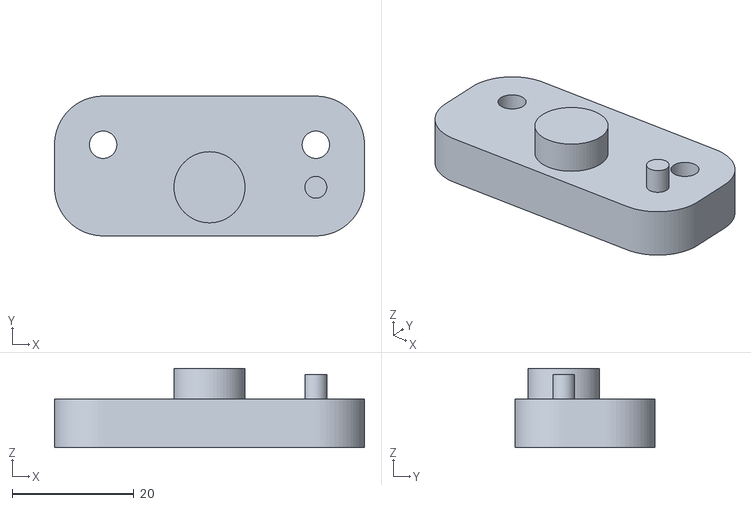
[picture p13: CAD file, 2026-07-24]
scanner_rig/stl/motor_drill_template.stl
51.0 x 23.0 x 13.0

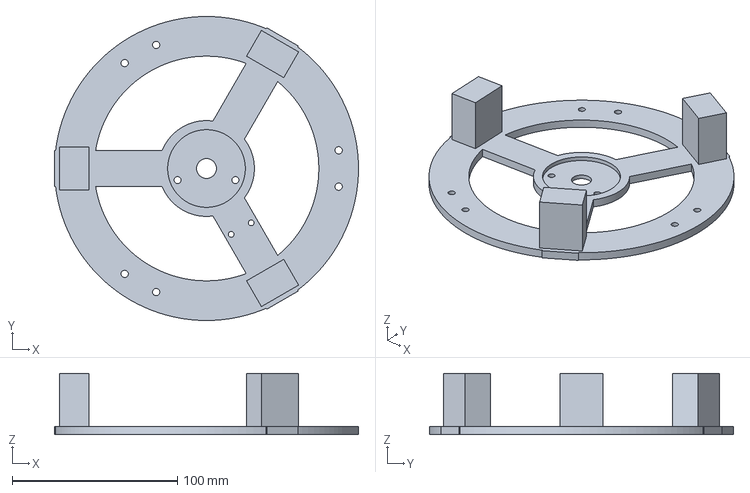
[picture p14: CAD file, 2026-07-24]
scanner_rig/stl/turntable_base_print.3mf
184.0 x 184.0 x 37.0 mm

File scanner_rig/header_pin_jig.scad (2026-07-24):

// ─────────────────────────────────────────────────────────────
// Header-pin soldering jig for the ESP32-C3 SuperMini
//
// Holds two 1x8 male header strips upright at the SuperMini's exact
// pin spacing so the board drops straight onto them for soldering —
// the same trick as plugging headers into a breadboard, just shaped
// for this one board so there's nothing to eyeball.
//
// Board mechanical spec (from the SuperMini datasheet): 22.52 x 18 mm,
// two rows of 8 pins, 2.54 mm pitch, rows 15.24 mm apart (0.6" — the
// same breadboard-spanning spacing as an Arduino Nano).
//
// USE: snap two 1x8 segments off a standard 2.54 mm break-away header
// strip. Push each strip LONG-pin-down into a row of holes until the
// plastic shoulder sits flat on the jig's top face — exactly how the
// strip would sit in a breadboard. The SHORT pins now point up above
// the jig by ~2.5 mm. Lower the SuperMini (component side up) onto
// them so its two rows of through-holes slide over the short pins.
// Tack-solder one corner pin on each row first, check the board sits
// flat and square, then solder the rest from the top. Lift the board
// off the jig (friction fit only, no glue) once cool.
//
// PRINTS as-is, flat on the bed, no supports.
// ─────────────────────────────────────────────────────────────

$fn = 32;

pins_per_row = 8;      // SuperMini header pin count per row
pitch        = 2.54;   // header pin pitch
row_spacing  = 15.24;  // row-to-row spacing (0.6", from datasheet)

margin       = 4;      // block margin beyond the outermost pin holes
corner_r     = 3;      // corner rounding
th           = 8.5;    // block thickness ~= header long-pin length, for full-depth grip
hole_d       = 1.0;    // friction-fit hole for 0.64 mm square header pins
                        // (ream to ~1.1-1.2 mm with a drill bit if too tight off your printer)
chamfer_d    = 1.8;    // top countersink so pins guide in easily
chamfer_h    = 0.6;

row_len   = (pins_per_row - 1) * pitch;
block_len = row_len + 2 * margin;
block_wid = row_spacing + 2 * margin;

module block_shape(h) {
    hull()
        for (x = [-1, 1], y = [-1, 1])
            translate([x * (block_len/2 - corner_r), y * (block_wid/2 - corner_r), 0])
                cylinder(r = corner_r, h = h);
}

module header_pin_jig() {
    difference() {
        block_shape(th);
        for (r = [-1, 1])
            for (i = [0 : pins_per_row - 1])
                translate([-row_len/2 + i * pitch, r * row_spacing/2, -1]) {
                    cylinder(d = hole_d, h = th + 2);
                    translate([0, 0, th - chamfer_h])
                        cylinder(d1 = hole_d, d2 = chamfer_d, h = chamfer_h + 1);
                }
    }
}

header_pin_jig();

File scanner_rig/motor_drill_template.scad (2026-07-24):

// ─────────────────────────────────────────────────────────────
// Motor ear-hole drill template  (for salvaging an already-printed base)
//
// Locates on TWO existing features of the printed base so it cannot shift
// or rotate while you drill:
//   • center pin  → drops into the Ø12 shaft hole (the true axis / datum)
//   • locator pin → drops into ONE existing old ear hole (Ø4.2 at 17.5,0),
//                   which pins the rotation
// It then guides a drill at the two NEW ear positions (±17.5, 7 mm off the
// old line).
//
// PRINTS as-is: plate flat on the bed, the two pins as short studs pointing
// up. No supports.
//
// USE: remove the motor. Set the base plate-side UP (the flat platter face).
// FLIP the template over so the pins point down: seat the center pin in the
// shaft hole and the locator pin in EITHER old ear hole (both work). When it
// sits flush, drill straight down through the two guide holes with a 4.4 mm
// bit (11/64").
// Deburr. Mount the motor over the NEW hole pair, ears bolted through with
// nuts inside the skirt. (The offset side is symmetric — just rotate the
// motor so its ears line up with the holes you drilled.)
// ─────────────────────────────────────────────────────────────

$fn = 64;

c2c          = 35;    // ear-hole spacing (matches turntable.scad)
perp         = 7;     // shaft → new-ear-hole line offset (matches turntable.scad)

th           = 8;     // template thickness = drill-guide length (keeps bit straight)
center_pin_d = 11.7;  // into the Ø12 shaft hole
center_pin_h = 5;
loc_pin_d    = 3.6;   // into an existing old Ø4.2 ear hole at (c2c/2, 0)
loc_pin_h    = 4;
guide_d      = 4.5;   // drill guide for the new holes (use a 4.4 mm bit)

module template() {
    difference() {
        // body plate on the bed (z = 0 .. th), rounded around all features
        hull() for (p = [[-c2c/2, 0], [c2c/2, 0], [-c2c/2, perp], [c2c/2, perp]])
            translate([p[0], p[1], 0]) cylinder(d = 16, h = th);
        // guide holes at the NEW ear positions, all the way through
        for (s = [-1, 1])
            translate([s * c2c/2, perp, -1]) cylinder(d = guide_d, h = th + 2);
    }
    // registration pins as studs on top (become the locators when flipped)
    translate([0,     0, th]) cylinder(d = center_pin_d, h = center_pin_h);
    translate([c2c/2, 0, th]) cylinder(d = loc_pin_d,    h = loc_pin_h);
}

template();

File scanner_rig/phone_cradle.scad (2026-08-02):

// ─────────────────────────────────────────────────────────────
// iPhone 16 Pro scanning cradle + arc stand
//
// The tray holds the phone in landscape and bolts between two
// arch-shaped "wings". The wings carry three pivot stations that
// lie on an ARC of constant radius about the object centre, so
// each station puts the camera at a different height AND a
// different distance back — higher and closer as the angle
// steepens — while a matching lock hole pitches the tray down by
// the same angle. Result: the camera always looks straight at the
// object centre from the same distance, on all three passes.
//
// Parts:
//   tray      x1  (unchanged — reuse an already-printed one)
//   wing      x2  print flat, 238 x 321 x 6, no supports (one at a time)
//   crossbar  x2  print flat
//   gauge     x1  setback stop — bridges the wing toes, turntable pushes
//                 back against it so the setback can't drift
//   chocks    x1 print, 2 parts — clamp either side of one turntable foot.
//                 With the gauge these pin the platter axis to the stand in
//                 every direction, so framing repeats between passes.
//   shim      x2  only when retargeting the arc at a taller object
//   stand         legacy flat stand, kept for reference only
//
// Hardware per setup: 2x M4x12 pivots + 1x M4x12 lock pin
// (self-tap into the tray bosses) + 4x M4x12 for the crossbars
// + 2x M4x12 lock screws for the foot chocks.
//
// Use: the camera shoots out the tray's back window. Turntable
// axis is y = 0, the stand stands at +y. To change pass, move the
// tray's 3 screws to the next station's hole pair.
// ─────────────────────────────────────────────────────────────

part = "assembly"; // ["assembly", "arc_assembly", "tray", "wing", "crossbar", "gauge", "shim", "stand"]

$fn = 64;

/* [Phone — iPhone 16 Pro] */
phone_l = 149.6;
phone_w = 71.5;
phone_t = 8.25;
fit     = 0.6;   // total clearance; use ~2.0 and a bigger phone_t if it wears a case

/* [Tray] */
wall   = 4;
back_t = 3;
lip    = 3;      // retaining tab overhang
border = 4;      // resting ledge around the camera window. Kept narrow so
                 // the phone contacts only the flat glass perimeter and the
                 // whole camera island passes through the window without
                 // touching the ledge — in either landscape orientation.
                 // The iPhone 16 Pro island is inset ~6 mm from the edges,
                 // so 4 mm leaves ~2 mm clearance. Camera-bump depth is
                 // irrelevant: the window is a through-hole, so the island
                 // protrudes out the back toward the turntable.

button_relief = true; // open the central span of both long walls so the
                      // iPhone's side buttons (Action/volume, Side/Camera
                      // Control) never bear on plastic; also serves as
                      // finger access. Orientation-agnostic.
relief_land   = 18;   // solid wall kept at each end of the long walls;
                      // registers the phone and backs the retaining tabs

/* [Pivot] */
boss_t = 6;
lock_r = 22;                  // lock-hole radius from the pivot
angles = [0, 15, 30, 45, 60]; // indexed tilt positions
pin_d  = 4.4;                 // through-holes in the stand (M4)
tap_d  = 3.6;                 // self-tap holes in the tray bosses

/* [Stand — legacy flat stand, superseded by the arc stand below] */
upright_t  = 5;
upright_w  = 70;
pivot_h    = 130;  // pivot height above the table — match your object's center height
base_t     = 5;
base_depth = 100;

/* [Arc stand — camera rides an arc centred on the object] */
// Tilting the tray alone only changes where the camera AIMS, not where it IS.
// To shoot down at angle θ and still have the object centred, the camera has
// to move along an arc of constant radius about the object centre: higher AND
// closer as θ grows. That also keeps framing, focus distance and scale
// identical on every pass, and it keeps the stand half as tall as a straight
// column would need to be (271 mm vs 519 mm to reach 65°).
//
//   camera at elevation θ:   y = cam_R·cos θ ,  z = obj_h + cam_R·sin θ ,  tilt = θ
//
// Turntable axis is y = 0; the stand stands at +y. Object centre is (0, obj_h).
//
// DATUM: every z here is measured from the DESK/TABLE the rig stands on, not
// from the platter — the wings sit on the same desk as the turntable, so they
// must share one origin. The platter top is 69.0 mm above the desk (measured
// from turntable.scad: legs 32 + plate 5 + platter_lift 26 + platter_t 6).
//
//        obj_h = platter_top + (object height)/2 = 69 + h/2
//
// You do NOT need a wing per object size. obj_h only fixes where the arc aims;
// what matters is the height difference between the wing's base and the object
// centre, so shim instead of reprinting:
//
//        shim = (object height)/2 + 69 - obj_h
//              + -> spacer under the WINGS (see the `shim` part)
//              - -> riser under the OBJECT, on the platter
//
// Default obj_h = 101 puts the zero-shim object at 64 mm, i.e. the sweet spot
// for 2x at cam_R = 200. No shim needed at all for 43..85 mm at 2x, or
// 23..105 mm at 1x (the wider frame is more forgiving).
platter_top = 69;           // platter surface above the desk — do not change
obj_h      = 101;           // object CENTRE above the DESK (= 69 + h/2)
cam_R      = 200;           // camera→object distance, constant along the arc
elevations = [15, 40, 65];  // the three camera positions (low / mid / high)

wing_t   = 6;    // wing plate thickness
band_in  = 10;   // band reaches this far inside the arc (material behind the
band_out = 30;   // camera only — nothing intrudes into the shot)
rail_h   = 14;   // bottom rail height
toe_y    = 100;  // front foot (clears the Ø184 turntable frame)
heel_y   = 290;  // rear foot — counters the forward lean of the arch
strut_w  = 18;   // rear diagonal width
xbar     = [16, 12];  // cross-bar cross-section

/* [Setback gauge — repeatable stand-to-turntable distance] */
// Moving a phone between stations nudges the stand, and any change in setback
// changes cam_R — so framing, scale and focus distance drift between passes.
// This bar bridges the two wing toes and gives the turntable a hard stop to be
// pushed back against, so the distance is set by geometry instead of by eye.
//
// It butts a turntable FOOT (outer face at leg_r + leg_x/2 = 89 in
// turntable.scad), with the base turned so one foot points at the stand.
//
// The contact is a FLAT face, deliberately. A flat touching the foot fixes only
// the fore/aft distance, so the turntable can STILL slide sideways to put the
// lens on the platter axis (README: "Aligning the lens with the turntable
// axis"). A pocket that captured the foot would fix the sideways offset too and
// fight that adjustment — the ~45-50 mm lens offset would be unreachable.
//
// Aim is forgiving: as the foot rotates its outer corner sweeps toward the
// contact, so being 10 deg off costs under 0.2 mm of setback (20 deg ~ 1.8 mm).
tt_foot_r  = 89;   // turntable foot outer radius (turntable.scad: leg_r+leg_x/2)
gauge_h    = 12;   // bar height — well under the foot's 32 mm, clears the
                   // Ø184 ring (starts at z=32) and the platter (z=63)
gauge_grip = 26;   // how far the side guides run back along the wing rails
gauge_wall = 5;    // guide wall thickness
gauge_fit  = 0.4;  // slip fit over the 6 mm wing rail
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

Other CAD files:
scanner_rig/stl/turntable_platter.stl
scanner_rig/stl/turntable_base.3mf
scanner_rig/stl/turntable_bracket.3mf
scanner_rig/turntable.scad
scanner_rig/stl/cradle_stand.stl
scanner_rig/stl/turntable_axle.stl
scanner_rig/stl/turntable_base.stl
scanner_rig/stl/turntable_base_print.stl
scanner_rig/stl/turntable_bracket.stl
scanner_rig/turntable.stl

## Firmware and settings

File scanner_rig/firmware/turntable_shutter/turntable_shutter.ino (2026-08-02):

// Automated scanning turntable: 28BYJ-48 via ULN2003 + BLE camera shutter.
//
// The ESP32 advertises as a Bluetooth keyboard. iOS treats a volume-up
// keypress as the shutter button while the Camera app is open, so each
// cycle is: rotate one increment -> settle -> snap.
//
// Board:   ESP32-C3 SuperMini (Arduino IDE, board package "esp32",
//          board "ESP32C3 Dev Module")
// Library: "ESP32-NimBLE-Keyboard" (wakwak-koba fork) + "NimBLE-Arduino".
//          The classic T-vK "ESP32 BLE Keyboard" uses Bluedroid and PANICS
//          at begin() on the ESP32-C3 (null deref in NimBLE HID setup, MTVAL
//          0x2c). The NimBLE fork is a drop-in — same <BleKeyboard.h> and
//          same API — but runs on the stack the C3 actually supports.
//          Install: Library Manager → "NimBLE-Arduino"; then add the fork
//          from https://github.com/wakwak-koba/ESP32-NimBLE-Keyboard
//          (Sketch → Include Library → Add .ZIP Library). Remove/avoid the
//          T-vK library so its BleKeyboard.h isn't picked up instead.
//
// Wiring (ULN2003 driver board):
//   IN1 -> GPIO 4      IN2 -> GPIO 5
//   IN3 -> GPIO 6      IN4 -> GPIO 7
//   Driver VCC -> 5V, GND -> GND
//
// NOTE: this targets the ESP32-C3 SuperMini specifically, not a classic
// ESP32 WROOM board. GPIO 18/19 aren't broken out on the C3 (used
// internally for native USB), so the stepper moved to GPIO 4-7. The
// onboard BOOT button is wired to GPIO9 on the C3 (a strapping pin) —
// GPIO0 has no button behind it on this board.
//
// Use: pair "ScanTable" in iPhone Bluetooth settings, open the Camera
// app, frame the object, then use the ESP32 BOOT button:
//
//   single press  scan — one revolution, 48 photos per paired phone
//                 (~3 min). Move the tray to the next arc station and
//                 press again, unless all three stations are loaded.
//   double press  dry run — one revolution in ~10 s, no photos, no
//                 phone needed. Use it to confirm the object stays in
//                 frame at every angle before committing to a scan.

#include <NimBLEDevice.h>   // for startAdvertising(); BleKeyboard.h doesn't pull it in
#include <BleKeyboard.h>

BleKeyboard bleKeyboard("ScanTable", "DIY", 100);

const int PINS[4] = {4, 5, 6, 7};     // ULN2003 IN1-4 (matches the wiring note)
const int BUTTON = 9;                 // BOOT button on the ESP32-C3 SuperMini
// Avoid GPIO 8 for a coil: it's a strapping pin (and the onboard LED on most
// C3 SuperMinis), so driving it can interfere with boot. GPIO 2 and 9 are
// also strapping pins — 9 is fine as the BOOT button (it has a pull-up).

// Drives however many iPhones are actually paired, 1 up to MAX_PHONES. This is
// a ceiling, not a requirement: nothing waits for a full set, and phones may
// join or drop at any time — each run fires whichever are connected.
//   1 phone  -> move the tray between the three arc stations, 3 revolutions
//   3 phones -> one tray per station, ONE revolution captures all 144 photos
// A BLE HID notify reaches every subscribed host, so a single keypress fires
// them all; the table is stationary ~3 s per step, so sync tolerance is about a
// second, not milliseconds.
// NimBLE defaults allow 3 simultaneous connections and 3 bonds.
const int   MAX_PHONES     = 3;

// THE reason a third phone silently fails to pair. Every bonded host stores one
// CCCD record per notify characteristic it subscribes to, and NimBLE keeps them
// all in ONE global array shared by every bond:
//     ble_store_config_cccds[MYNEWT_VAL_BLE_STORE_MAX_CCCDS]   (default 8)
// This HID device exposes 3 notify characteristics — keyboard report, media-key
// report, battery level — so N phones need 3N records. Two phones fit in 8;
// three need 9 and the store overflows, so phone 3 can't subscribe.
//
// Raised to 16 by build_opt.h next to this sketch. Note it must override
// MYNEWT_VAL_BLE_STORE_MAX_CCCDS and NOT CONFIG_BT_NIMBLE_MAX_CCCDS: nimconfig.h
// includes the core's sdkconfig.h, which defines the CONFIG_ name unconditionally
// and would clobber a -D. The MYNEWT_VAL_ alias is #ifndef-guarded everywhere,
// so a command-line define wins. This assert turns a lost or ineffective
// build_opt.h into a build error rather than a 2-phone mystery.
static_assert(MYNEWT_VAL_BLE_STORE_MAX_CCCDS >= 3 * MAX_PHONES,
              "CCCD store too small for MAX_PHONES: need 3 records per phone. "
              "Check build_opt.h sits next to this .ino and defines "
              "MYNEWT_VAL_BLE_STORE_MAX_CCCDS.");
const int   PHOTOS_PER_REV = 48;      // 48 per pass; x3 passes (or x3 phones)
const long  STEPS_PER_REV  = 4096;    // 28BYJ-48, half-stepping
const int   STEP_DELAY_US  = 1200;    // slower = more torque
const int   SETTLE_MS      = 1500;    // vibration die-down before the shot
// Slack taken up before the first shot so frame 1 isn't short. ~6 deg of D-bore
// play plus gear backlash; 100 half-steps is ~8.8 deg, comfortably over it.
// Costs nothing to overshoot — it only pre-loads the mechanism.
const long  BACKLASH_STEPS = 100;
const int   EXPOSURE_MS    = 1800;    // time for iPhone to capture + save

// Double-press = one revolution with no photos: a dry run for checking that the
// object never clips at any angle before committing to a real scan, and for
// exercising the mechanism before any phone is paired. It runs continuously
// rather than step-and-pause, so ~10 s instead of ~3 min — slower per step than
// a scan, since nothing has to settle and a gentler speed is easier to watch
// (and kinder to a tall or unbalanced object).
const int   DOUBLE_MS      = 400;     // window to catch the second press
const int   DRY_STEP_US    = 2500;    // ~10 s per revolution

// Never hand-count connections: iOS's HID pairing does connect → bond →
// reconnect, so connect/disconnect callbacks don't reliably pair up and a
// counter drifts. The server knows the truth — ask it.
int hostsUp() {
  NimBLEServer* s = NimBLEDevice::getServer();
  return s ? s->getConnectedCount() : 0;
}

// half-step sequence
const uint8_t SEQ[8] = {0b1000, 0b1100, 0b0100, 0b0110,
                        0b0010, 0b0011, 0b0001, 0b1001};
long stepIndex = 0;

void stepOnce(int us) {
  stepIndex = (stepIndex + 1) % 8;
  for (int i = 0; i < 4; i++)
    digitalWrite(PINS[i], (SEQ[stepIndex] >> (3 - i)) & 1);
  delayMicroseconds(us);
}

void coilsOff() {                     // release the rotor (see rotateSteps)
  for (int i = 0; i < 4; i++) digitalWrite(PINS[i], LOW);
}

// Do NOT cut the coils between shots.
//
// The drive train has real lost motion: the platter's D-bore on the 28BYJ-48's
// flatted shaft gives ~6 deg of free rotation on its own (0.4 mm of clearance
// across a 3 mm flat is a tiny moment arm, so it becomes a big angle), plus the
// motor's own plastic gear backlash on top. That is up to ~80% of a 7.5 deg
// step sitting in the mechanism.
//
// Turning one direction only, that slack is taken up ONCE at the start and then
// stays taken up — but only while the rotor is held. Releasing between shots
// lets the platter settle back into the slack under friction and any imbalance
// in the object, and the next move spends part of its travel re-taking it up:
// some advances land full, others short, unpredictably. So hold position for
// the whole revolution and release only at the end.
//
// Holding costs ~200 mA per energised phase and the motor runs warm — that is
// well within its continuous rating for a ~3 minute revolution.
void rotateSteps(long n, int us) {
  for (long i = 0; i < n; i++) stepOnce(us);
}

void setup() {
  Serial.begin(115200);
  // The C3 SuperMini has NO USB-UART bridge — it's native USB, so `Serial`
  // only reaches the USB port when the sketch is built with
  // "USB CDC On Boot: Enabled" (Tools menu). Left Disabled (the board
  // default) Serial goes to UART0 on GPIO 20/21 and the monitor stays blank.
  // The host also enumerates the CDC port a beat after boot, so wait for it —
  // bounded, since the rig must still run when nothing is plugged in.
  for (unsigned long t0 = millis(); !Serial && millis() - t0 < 2000; ) delay(10);
  for (int i = 0; i < 4; i++) pinMode(PINS[i], OUTPUT);
  pinMode(BUTTON, INPUT_PULLUP);
  coilsOff();

  // The library stops advertising once a host connects, so for multiple phones
  // it has to be restarted. Do NOT restart it from these callbacks: they run in
  // the NimBLE host task while the connect event is still being processed, the
  // call can fail there, and a lost restart is unrecoverable — the next phone
  // never sees an advertisement. keepAdvertising() in loop() handles it
  // instead, so a failed attempt is simply retried. Callbacks only log.
  // Pair the phones ONE AT A TIME: wait for each to report connected before
  // starting the next, otherwise they race for the same advertising slot.
  bleKeyboard.onConnect([]() {
    Serial.printf("phone connected — %d of up to %d\n", hostsUp(), MAX_PHONES);
  });
  bleKeyboard.onDisconnect([]() {
    Serial.printf("phone dropped — %d still connected\n", hostsUp());
  });

  bleKeyboard.begin();
  Serial.printf("Advertising as 'ScanTable' — pair 1 to %d iPhone(s), one at a "
                "time. Press BOOT to run with whatever is connected.\n",
                MAX_PHONES);
}

// Keep advertising alive whenever there's a free slot, retrying until it takes.
// Called every loop, so a restart that fails inside the BLE stack just gets
// tried again a moment later instead of stranding the remaining phones. Since
// this only stops at MAX_PHONES, a second or third phone can be added at any
// time — including between revolutions — without touching the firmware.
void keepAdvertising() {
  static unsigned long lastTry = 0;
  if (hostsUp() >= MAX_PHONES) return;
  NimBLEAdvertising* adv = NimBLEDevice::getAdvertising();
  if (!adv || adv->isAdvertising()) return;
  if (millis() - lastTry < 500) return;           // don't hammer the stack
  lastTry = millis();
  Serial.printf("advertising (%d connected)\n", hostsUp());
  NimBLEDevice::startAdvertising();
}

// Returns 0 = nothing, 1 = single press, 2 = double press. A single press only
// resolves after the double-press window closes, which costs DOUBLE_MS before a
// scan starts — unnoticeable next to a 3 minute revolution.
int readButton() {
  if (digitalRead(BUTTON) == HIGH) return 0;
  delay(30);                                       // debounce
  if (digitalRead(BUTTON) == HIGH) return 0;       // bounce or noise, not a press
  while (digitalRead(BUTTON) == LOW) delay(10);    // wait for release

  for (unsigned long t0 = millis(); millis() - t0 < DOUBLE_MS; ) {
    if (digitalRead(BUTTON) == LOW) {
      delay(30);
      while (digitalRead(BUTTON) == LOW) delay(10);
      return 2;
    }
    delay(5);
  }
  return 1;
}

// One revolution, no photos, no phone required. Still takes up the backlash
// first so the platter turns exactly as it would in a scan, and holds the coils
// throughout for the same reason a scan does.
void dryRun() {
  Serial.println("Dry run — one revolution, no photos. Watch for clipping.");
  rotateSteps(BACKLASH_STEPS, DRY_STEP_US);
  rotateSteps(STEPS_PER_REV, DRY_STEP_US);
  coilsOff();
  Serial.println("Dry run complete.");
}

void loop() {
  keepAdvertising();

  int press = readButton();
  if (press == 0) { delay(20); return; }
  if (press == 2) { dryRun(); return; }

  // Run with whatever is paired — one phone is a perfectly good scan, it just
  // takes three revolutions instead of one. Only a completely empty set is an
  // error, since then the shutter would go nowhere.
  int phones = hostsUp();
  if (phones < 1) {
    Serial.println("No phone connected — pair 'ScanTable' from iPhone Bluetooth "
                   "settings, then press BOOT.");
    return;
  }

  Serial.printf("Starting revolution — firing %d phone(s) per step…\n", phones);

  // Take up the drive-train slack BEFORE the first shot, in the same direction
  // the revolution runs. Without this the first advance or two are short while
  // the backlash closes, and those frames sit at the wrong angle. These steps
  // are deliberately not counted against STEPS_PER_REV — they buy motion in the
  // mechanism, not rotation of the platter.
  rotateSteps(BACKLASH_STEPS, STEP_DELAY_US);
  delay(SETTLE_MS);

  long remainder = STEPS_PER_REV;
  for (int shot = 0; shot < PHOTOS_PER_REV; shot++) {
    long inc = remainder / (PHOTOS_PER_REV - shot);  // distributes rounding
    remainder -= inc;
    rotateSteps(inc, STEP_DELAY_US);
    delay(SETTLE_MS);
    // One notify reaches every subscribed host, so all phones fire together.
    bleKeyboard.write(KEY_MEDIA_VOLUME_UP);          // shutter
    int now = hostsUp();
    if (now < phones) Serial.printf("  ! phone dropped mid-run — %d left\n", now);
    Serial.printf("Shot %d/%d  (x%d phones)\n", shot + 1, PHOTOS_PER_REV, now);
    delay(EXPOSURE_MS);
  }
  coilsOff();                          // released only now the run is over
  // Report against the phones that actually fired, not a configured target.
  int done = hostsUp();
  Serial.printf("Revolution complete — %d photos captured.%s\n",
                PHOTOS_PER_REV * done,
                done >= 3 ? " All three stations covered."
                          : " Move the tray to the next station and run again.");
}

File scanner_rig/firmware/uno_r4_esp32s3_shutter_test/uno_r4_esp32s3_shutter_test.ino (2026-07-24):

// BLE camera-shutter test — flashed directly to the Uno R4 WiFi's onboard
// ESP32-S3 connectivity module (NOT the main Renesas RA4M1).
//
// The Uno R4 WiFi's WiFi/BLE coprocessor IS a standalone ESP32-S3, wired to
// its own USB-JTAG/Serial port. Putting it into download mode and flashing
// it directly (bypassing the RA4M1) turns it into a normal ESP32-S3 dev
// board for as long as this sketch is on it — good for validating the BLE
// keyboard shutter trick from firmware/turntable_shutter before committing
// to the ESP32-C3 SuperMini.
//
// Board:   ESP32S3 Dev Module (Arduino IDE, board package "esp32")
// Library: "ESP32 BLE Keyboard" by T-vK (same as turntable_shutter)
//
// ENTER DIRECT-FLASH MODE (see the official Arduino tutorial for the exact
// header/pin diagram: docs.arduino.cc/tutorials/uno-r4-wifi/esp32-upload):
//   1. Unplug the board.
//   2. Short GND to the "Download" pin on the 3x2 header near the USB-C
//      connector (silkscreen-labelled) with a jumper wire.
//   3. Plug in USB while shorted — it should enumerate as
//      "USB JTAG/serial debug unit", NOT the normal Uno R4 port.
//   4. Remove the jumper, select board "ESP32S3 Dev Module" and that new
//      port, then upload this sketch as usual.
//   5. Unplug/replug once more to reboot into the sketch normally.
//
// RESTORE normal Uno R4 WiFi behaviour afterward (WiFiS3, etc.) via
// Arduino IDE: Tools > Firmware Updater > UNO R4 WiFi > Check Updates.
// The RA4M1 (running uno_r4_stepper_test.ino via the main USB port) is
// completely unaffected by any of this — the two chips are independent.
//
// Use: open Serial Monitor at 115200 baud on the new JTAG/serial port.
// Pair "ScanTable-Test" from the iPhone's Bluetooth settings, open the
// Camera app, then type 's' + Enter to fire the shutter (volume-up
// keypress). Kept as a separate device name from the real "ScanTable" so
// the two don't collide in your iPhone's paired-devices list.

#include <BleKeyboard.h>

BleKeyboard bleKeyboard("ScanTable-Test", "DIY", 100);

void setup() {
  Serial.begin(115200);
  bleKeyboard.begin();
  Serial.println("Advertising as 'ScanTable-Test' — pair from the iPhone.");
  Serial.println("Type 's' + Enter to fire the shutter once connected.");
}

void loop() {
  if (Serial.available() && Serial.read() == 's') {
    if (!bleKeyboard.isConnected()) {
      Serial.println("Not paired yet — connect from iPhone Bluetooth settings.");
    } else {
      bleKeyboard.write(KEY_MEDIA_VOLUME_UP);
      Serial.println("Shutter fired.");
    }
  }
}

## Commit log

2026-07-24 Add open-capture scanning rig and photogrammetry CLI
    Working end-to-end DIY object scanner:
    - photogrammetry.swift: macOS Object Capture CLI (photos -> USDZ)
    - scanner_rig: parametric OpenSCAD turntable, phone cradle, snap-in bearing
    axles, drill jig; all print without supports
    - firmware: ESP32-C3 BLE shutter + 28BYJ-48 stepper control, with verified
    NimBLE library setup (LIBRARIES.md)
    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
    [cradle_stand.3mf, cradle_stand.stl, cradle_tray.stl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]
2026-07-24 Replace flat cradle stand with an arc-following wing stand
    The old stand held the camera at a fixed height, so tilting the tray only
    changed where the camera aimed, not where it was — at 40deg it pointed at the
    tabletop in front of the object. Only the 0deg pass actually worked.
    The camera now rides an arc of constant radius about the object centre:
    y = cam_R*cos(t) z = obj_h + cam_R*sin(t) tilt = t
    Higher AND closer as the angle steepens. Besides keeping framing, scale and
    focus distance identical across passes, this is what makes the stand a sane
    size: reaching 65deg on the arc needs 271mm of height, versus 519mm for a
    straight column 200mm back.
    New parts (the tray is unch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
    [cradle_arc_crossbar.stl, cradle_arc_shim.stl, cradle_arc_wing.stl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]
2026-08-02 Drive 1-3 phones per run, and remove the platter's coupling play
    Shutter: the firmware now fires whatever is paired rather than waiting for a
    fixed count. MAX_PHONES is a ceiling, not a requirement — it keeps advertising
    while a slot is free, so phones can join or drop at any time (including between
    revolutions) and each run fires whichever are connected. One BLE HID notify
    reaches every subscribed host, so a single keypress trips all of them; the table
    stands still ~3s per step, so sync tolerance is ~1s rather than milliseconds.
    With one tray per arc station a single revolution captures all 144 photos.
    Three phones need a bigger CCCD store. Each bonded host stores one record per
    notify c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
    [cradle_arc_crossbar.stl, cradle_foot_chocks.stl, cradle_setback_gauge.stl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]
2026-08-02 Add a photo-free dry run on double-press
    Double-pressing BOOT turns the platter one full revolution in ~10s without
    firing any shutter, and without needing a phone paired. It exists for the
    framing check the README asks for — an object's silhouette changes width as it
    rotates, so it has to be framed for its widest profile, and the only way to know
    is to watch a full turn. Previously that meant spinning the platter by hand or
    burning a real 3 minute scan to find out.
    Runs continuously rather than step-and-pause since nothing has to settle, but at
    a slower per-step rate than a scan (2500us vs 1200us): easier to watch, and
    gentler on a tall or unbalanced object. Still takes up the backlash f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
    [turntable_shutter.ino]
